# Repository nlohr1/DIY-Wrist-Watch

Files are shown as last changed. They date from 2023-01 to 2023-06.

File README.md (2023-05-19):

# DIY-Wrist-Watch
### Small 3D-Printed OLED-Clock with RTC and ATmega328-chip, based on Arduino-code

Small OLED-Clock with the small **8-pin** Real-Time chip DS3231**MZ** and the commonly known (Arduino) ATmega328 uController chip,
in conjunction with a 128x64px OLED-Display (SSD1306-chip) - displaying Date, Time, (Battery)-Voltage and Skin-Temperature.

----
**OLED-Clock Case & Foto:**  
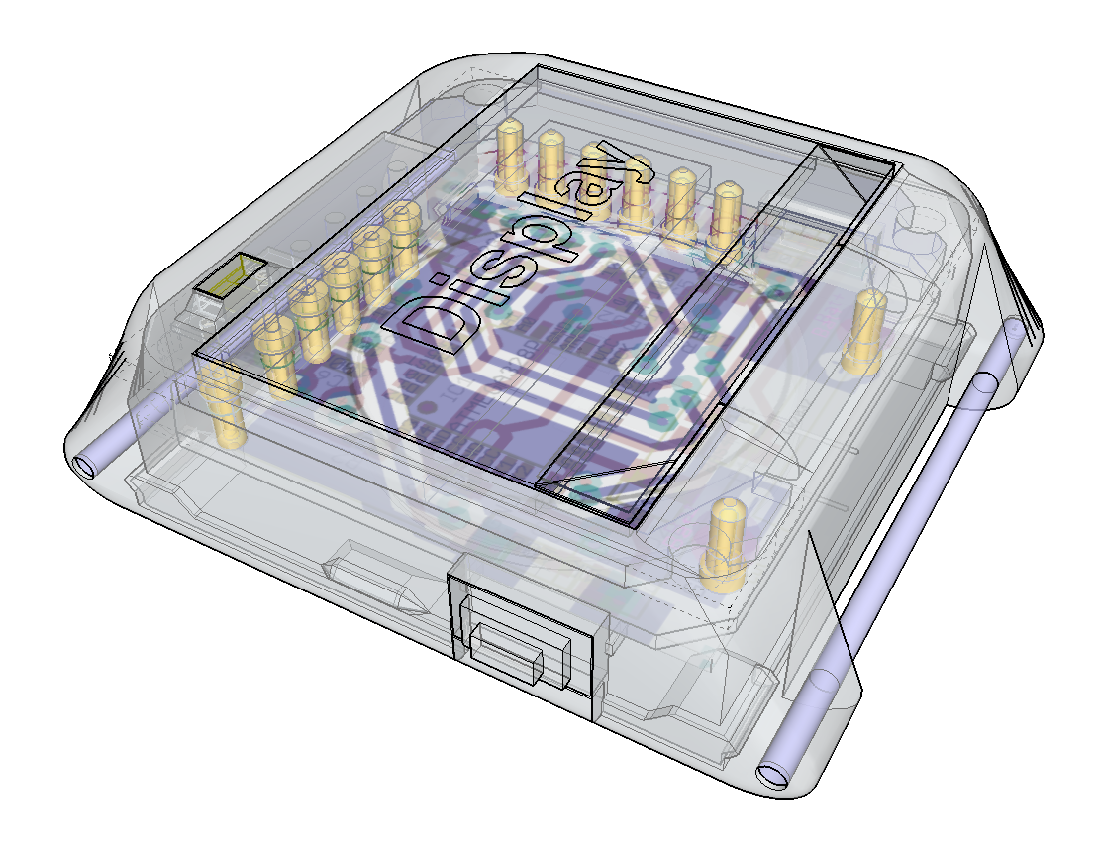
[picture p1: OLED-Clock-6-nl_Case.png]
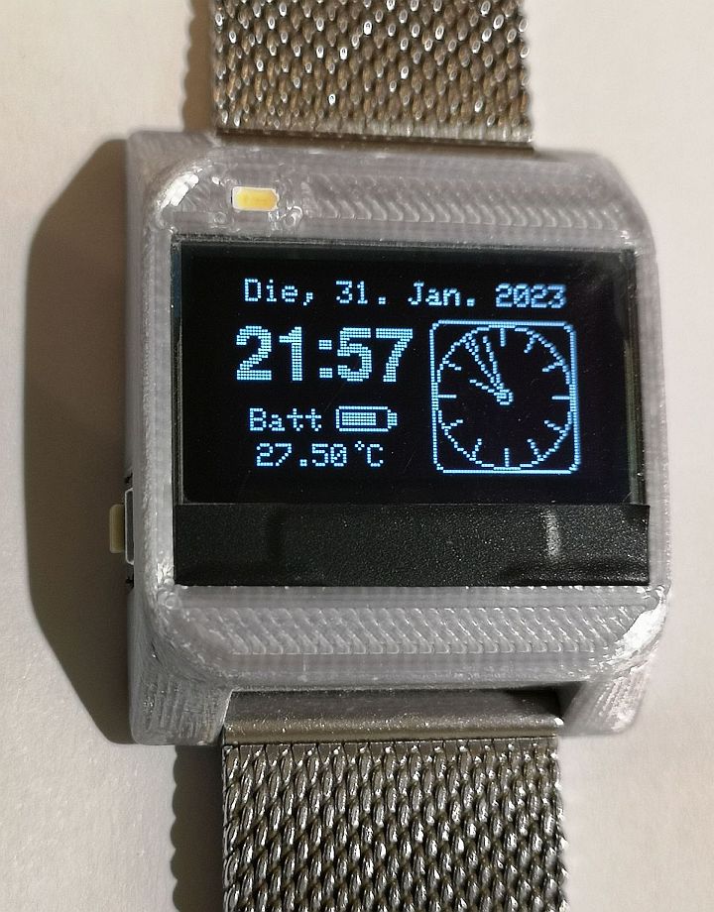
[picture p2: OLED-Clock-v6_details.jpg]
   

**Schematic:**  
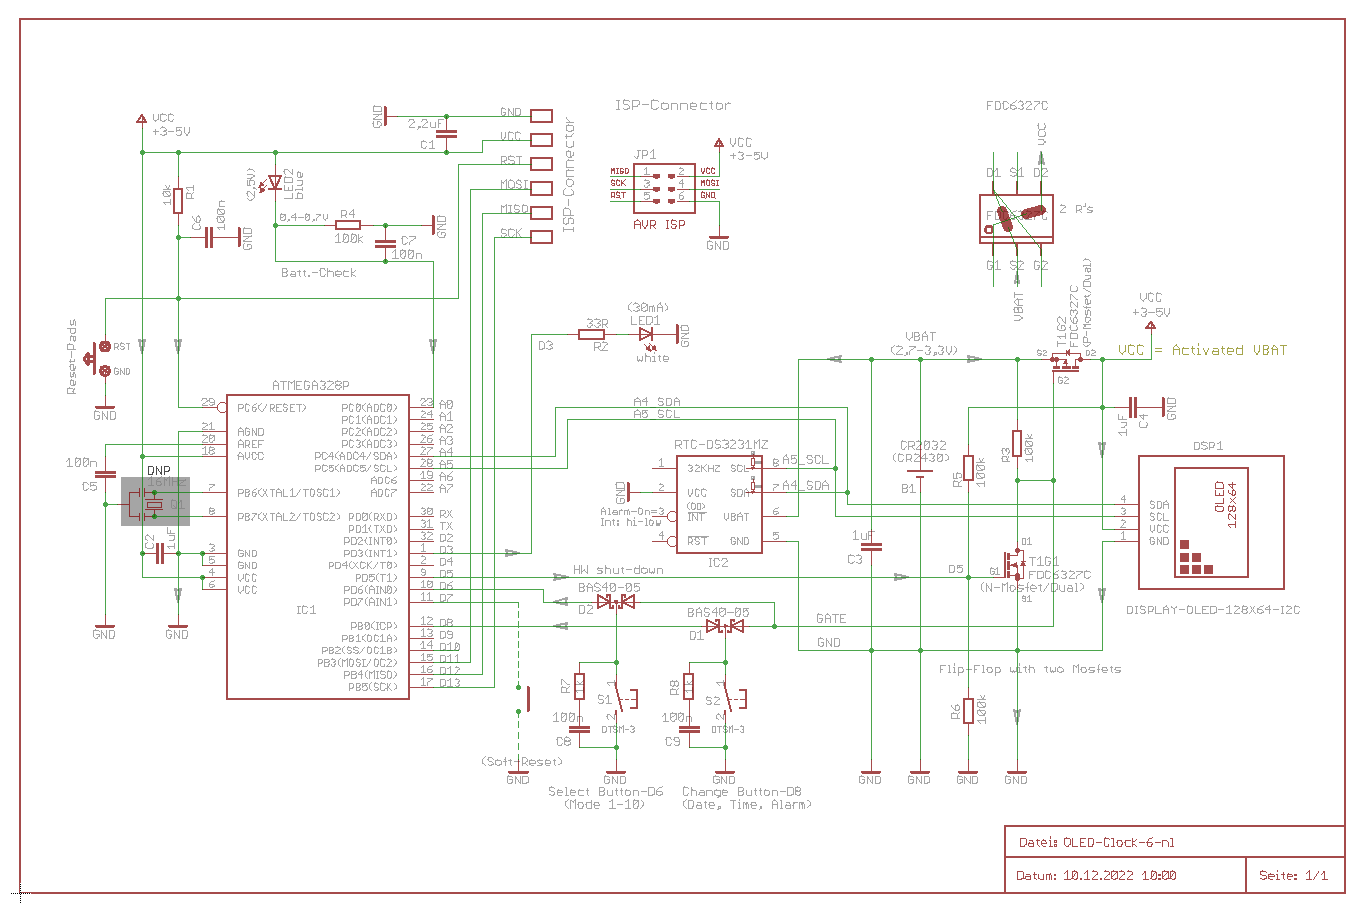
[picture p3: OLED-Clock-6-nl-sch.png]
  

**PCB-Layout:**  
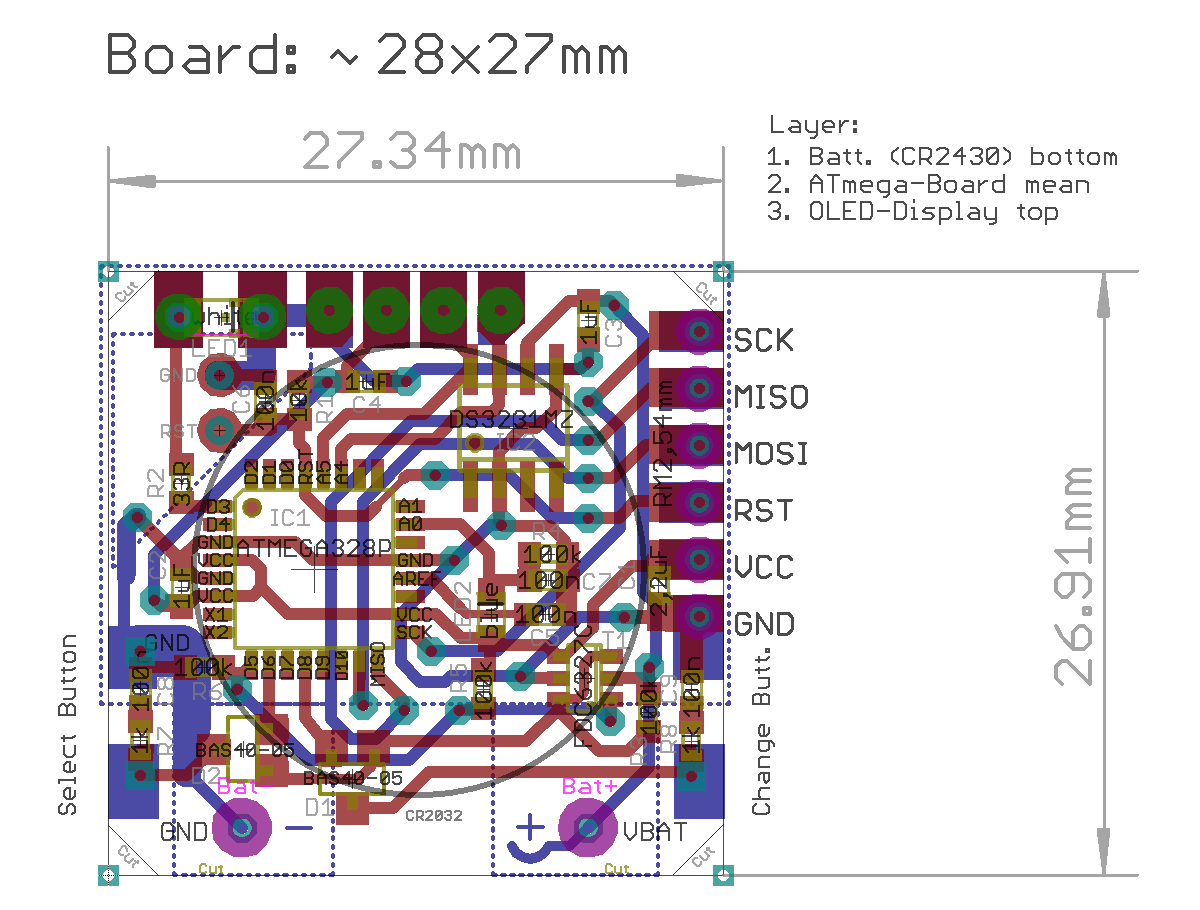
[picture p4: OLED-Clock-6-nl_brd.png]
  
Att: Push-Buttons soldered on PCB-background! - Female Socket-headers (yellow bushings) soldering: see "OLED-Clock-6-nl_Case.png"!

----
### Partlist (BOM) for "OLED-Clock-6-nl.sch":  
<pre><b><code>Qty.  Components      Value          Description                                        Package</code></b><code>
1x     C1              2,2uF          Capacitor, SMD                                     C0603
3x     C2,C3,C4        1uF            Capacitor, SMD                                     C0603
5x     C5,C6,C7,C8,C9  100n           Capacitor, SMD                                     C0603
2x     D1,D2           BAS40-05(W)    Dual-Schottky-Diode, low-leakage (1uA), SMD        SOT23 (-323-R)
1x     IC1             ATMEGA328P     8-bit Microcontroller (4x8 = 32 Pin), SMD          TQFP32-08
1x     IC2             DS3231MZ       RTC Real-Time Clock (8-Pin), SMD                   SO08
1x     JP1             AVR-ISP-6      AVR ISP-6 Serial Programming Header                AVR-ISP-6
1x     LED1            cool-white     Osram-LED-Duris-E3, 2.240mcd, 3V/30mA, SMD-3014    Chipled 1206
1x     LED2            blue           High-Efficiency LED, 2.5V-forward-voltage, SMD     Chipled 0805
1x     MD1             OLED-Display   I2C OLED-Module 0.96", (SSD1306 chip), SMD         128x64px
1x     R1              10k            Resistor, SMD                                      R0603
1x     R2              33R            Resistor, SMD                                      R0603
4x     R3,R4,R5,R6     100k           Resistor, SMD                                      R0603
2x     R7,R8           1k             Resistor, SMD                                      R0603
2x     S1,S2           Push-Button    Micro Tactile Switch 12V, 50mA, SMD                3.7x6x2.5mm
1x     T1              FDC6327C       Dual N+P-Channel Mosfet, SMD                       SOT23-6
14x    Socket          1x40 Pin       Female Socket-header, short (L:7.0mm, hole:0.6mm)  RM:2,54mm
1x     Board           FR4 #0.8mm     Mainboard, 2-layer (Cu 35um), #0.8mm               27.3x26.9mm
1x     Case            PLA or PETG    3D printed, 0.13mm layer-height, 100% Infill       31x36x10mm
1x     Lid             PLA or PETG    Bottom-Lid, case-latching                          29x28x2mm
1x     Strap           Inox           20mm Quick Release Milanese Mesh Watch Band        width: 20mm
2x     Wire            Inox or Steel  Inox or Galvanized Steel-Wires ø1.2mm              L: 29mm
2x     Bushing         Inox or Steel  Inox- or Brass-Bushing, ø1.8/1.5 mm                L: 20mm
</code></pre>   

----
Both, Micro-Processor and OLED are switched-on at Button-press, and off/disconnected from Battery **per hardware** (Schmitt-Trigger Transistor-circuit) after about 8 seconds, so that the only remaining consumption comes from RTC-chip (in stand-by-mode), consuming less than 1uA.  

I resigned to use the uControllers software-"power-down"-function, because this does not disconnect the OLED-display(chip) and other chips on board from Battery, which are causing additional power-consumptions.  
Current-Leakages are minimized through the double-mosfet FDC6237 (small Gate-Capacitances and Gate Threshold Voltages with 1-2V) and two double-diodes (BAS40-05W) with very small leakage-currents of 20nA.  
With this configuration the CR2032-Lithium-Battery lasts more than 2 years (proved! - using the clock-display about 10 times/day).

The Clock additionally provides a calendar, displaying the actual month(days) and a relatively bright Flashlight-LED, consuming only about 10mA.

Two Buttons are handling the Display-"On", Calendar, FlashLight-On/Off and Set/Reset of the Clock, meanwhile Display-"Off" is done automatically after 8 seconds.
The code is subdivided in several sections, with jump-markers: §0, §1, §2... explained in the code-head.  
I commented every line of the software, so it's possible to understand and modify it (at your own "risk")...  
File "OLED-Watch-6-nl-Manual.txt" provides a short user-manual list.  

The Software program-code (Arduino-based C++) is flashed through an ISP-Programmer to the ATmega328-Chip - **without bootloader**, to save start-time.  
To flash the chip I use the known **avrdude** as command-line-program, flashing the (Arduino-compiled) resulting hex-file with an ISP-Programmer (USBasp or similar), this programmer connected on one side through USB to my Notebook and on the other through a 6-pole ISP-Connector-Socket to the 6 Clock-pcb-board bushings.  

Avrdude command lines to flash the code into the ATmeag328-chip are explained also on the end of the program-file:  

> **"OLED-Clock-w-Led-and-Calendar.ino"** *(open/edit this file with a Text-Editor like Notepadd++)*  
> &nbsp; or directly in the Arduino-GUI, then compile it and

use the .hex-result in following command-line:  
> avrdude.exe -v -V -p m328p -c usbasp -B10 -e -D -U flash:w:OLED-Clock-w-Led-and-Calendar.ino.hex:i

The Case, Lid and battery-Holder are 3D-Printed with 0.13mm Layer-height and 100% Infill (PLA: 210°C / 60°C). I provided .stl-files of case, lid and battery-holder, also the corresponding .gcode-files for a medium 3D-Printer (bed-size about: 220 x 220 mm), as beeing Prusa-MK3 or similar printers like Anycubic-Pro, etc. (negligible differences in bed-sizes).

- Sliced with Prusa-Slicer - my profile-file: "prusaslicer_config.ini" - you may load it with the Hotkey [Ctr+L] into the Prusa-Slicer...  

- PCB schematic and Layout: Eagle 7.4
- Prototype etched with 0.8mm FR4-board with Toner-Direct methode (2 layers: first CNC-drilled the FR-material, (blank/fine-sanded + cleaned with acetone), then transferred the layout with toner-transfer-paper: 2 layers fixed/congruented on the 4 outer-edges/holes with ø0.4mm needles, this needles exchanged with ø0,4mm clamping-wire, fixing the paper on the FR4-board also with kapton-band on top and both sides, this "sandwitch" then toner-laminated with a 200°C modified laminator, etched in sodium persulfate at 70-80°C (etching-result in ≈ 5-10 min) + finally hot-tinned both sides with a flat soldering iron.
---

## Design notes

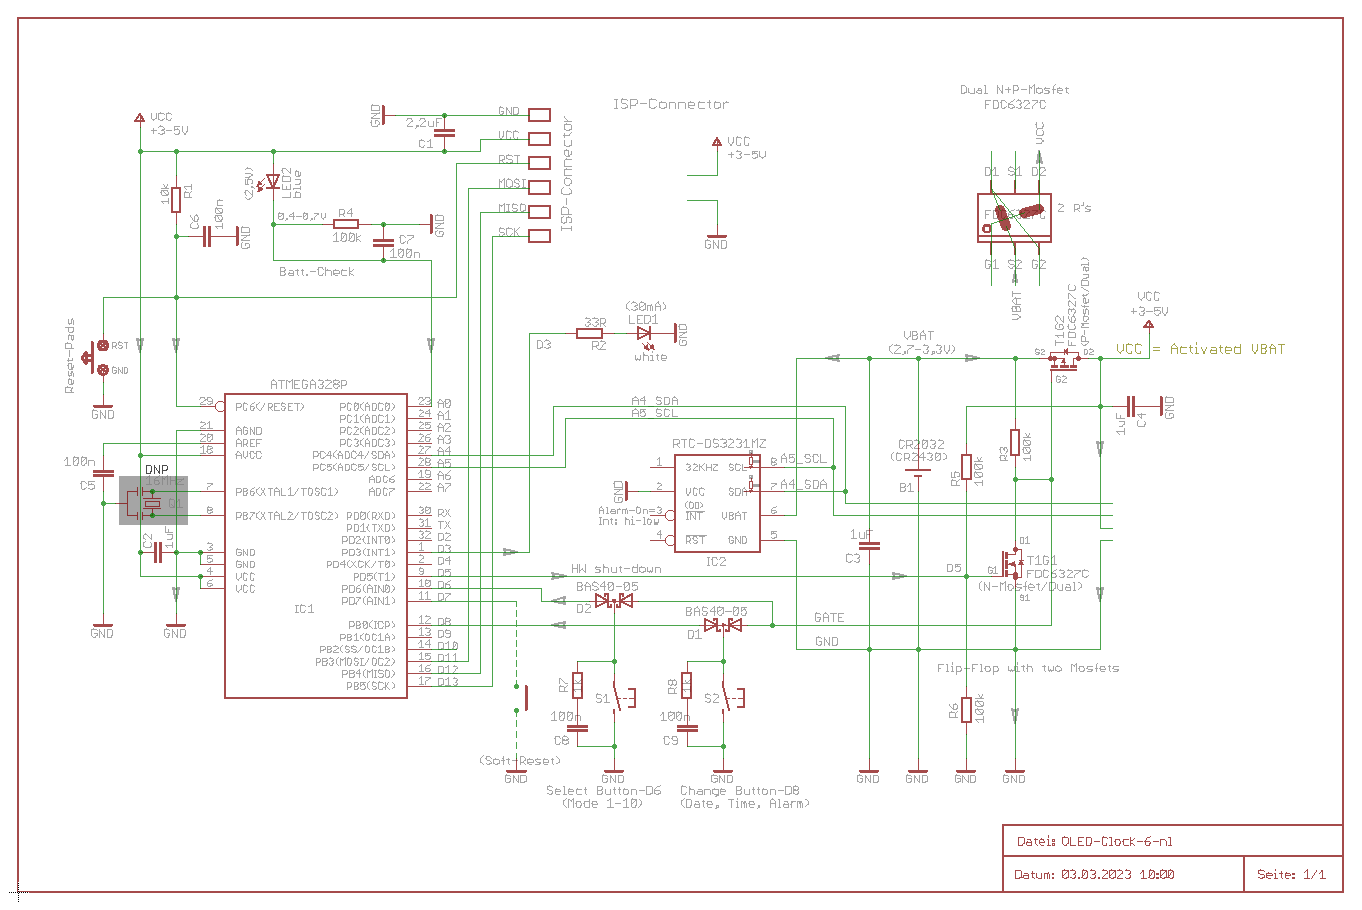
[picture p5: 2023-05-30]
OLED-Clock-6-nl_sch.png

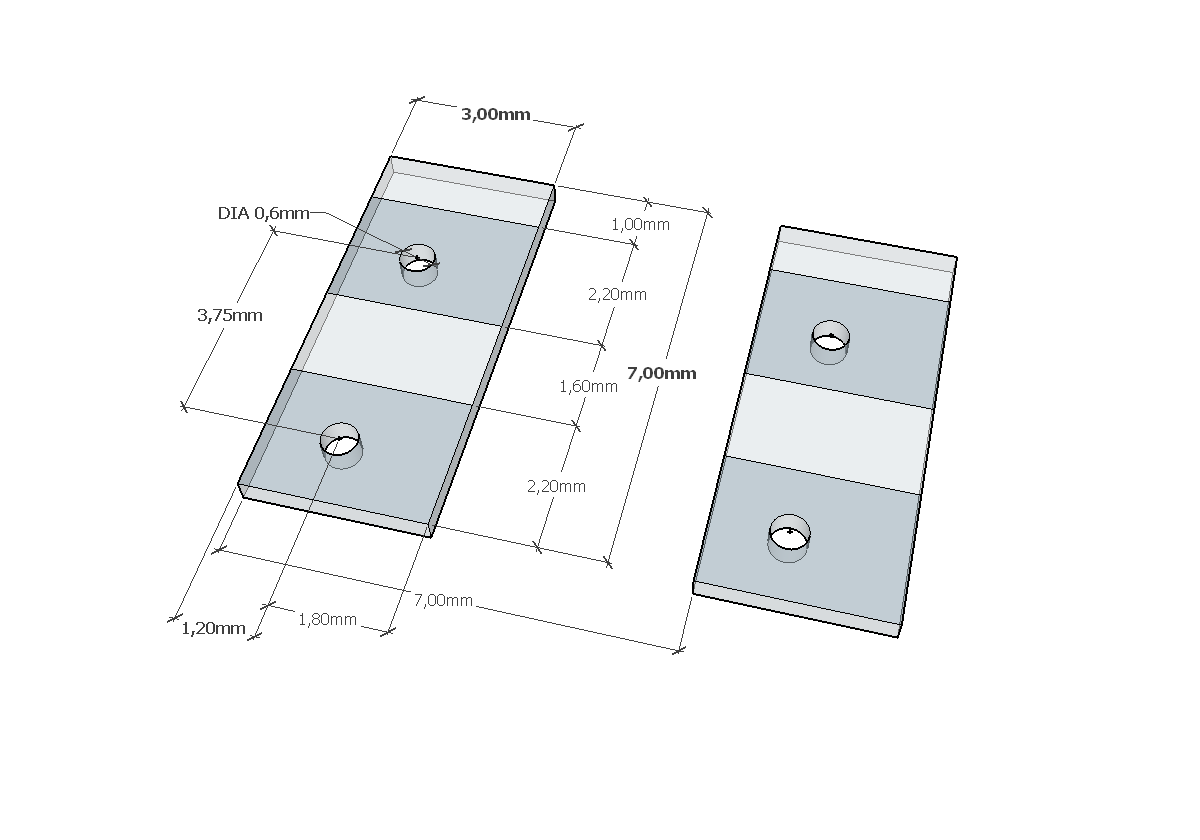
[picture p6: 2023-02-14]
LED-Platinchen_04mm_3x7mm.png

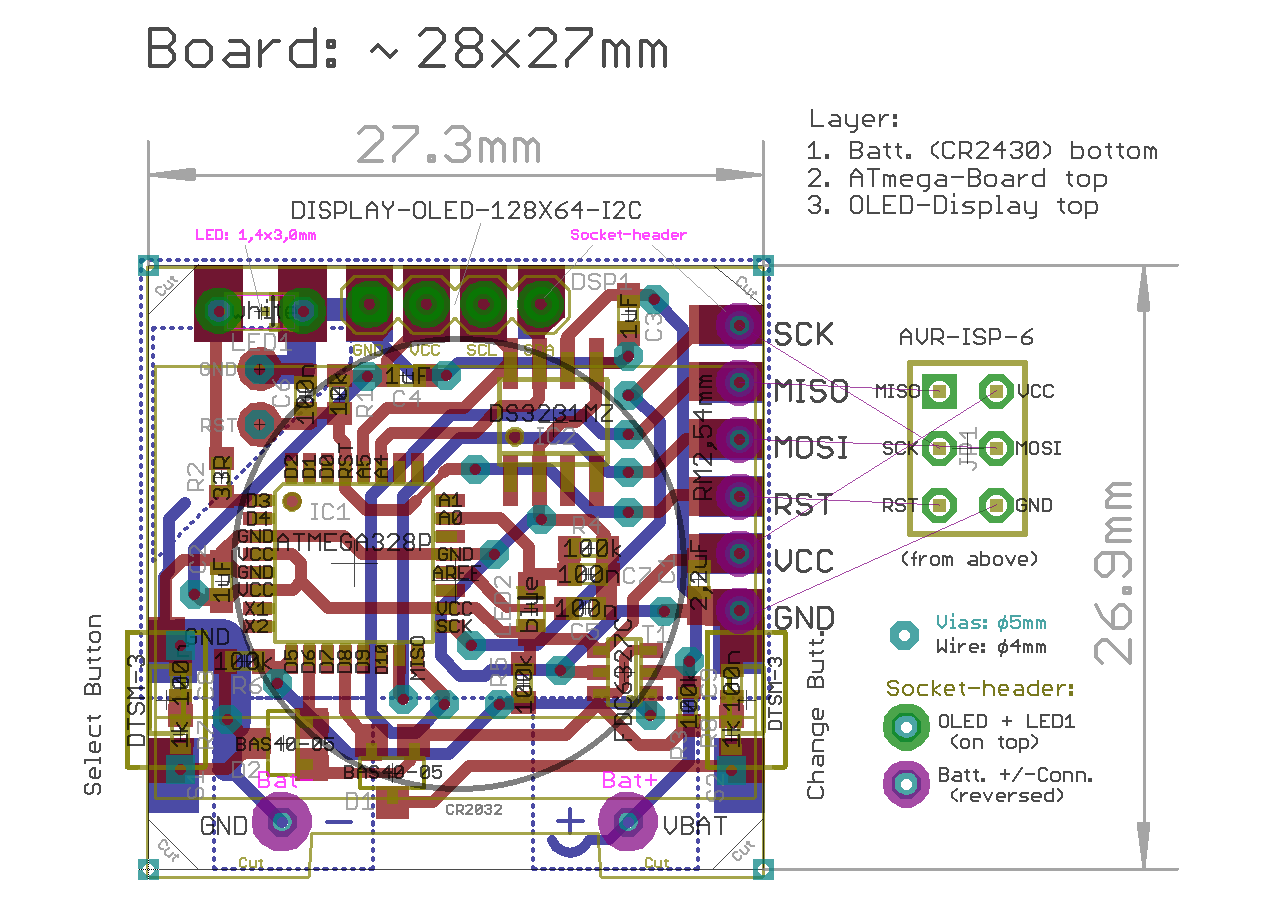
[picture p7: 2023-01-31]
OLED-Clock-6-nl-brd.png

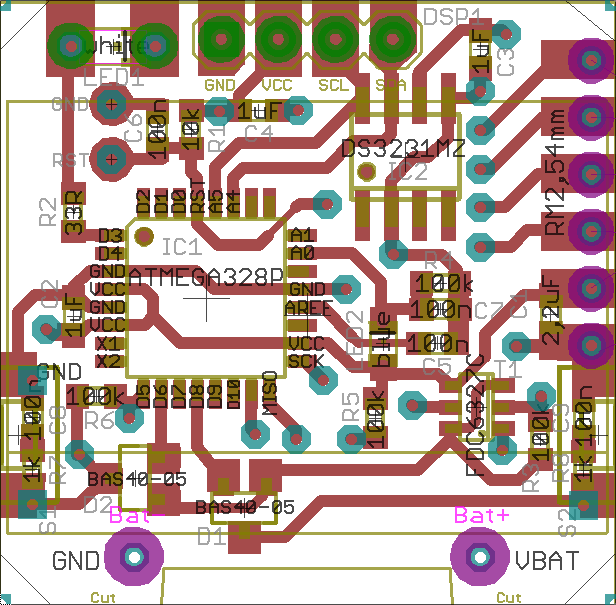
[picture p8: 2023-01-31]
OLED-Clock-6-nl-Board_Top.png

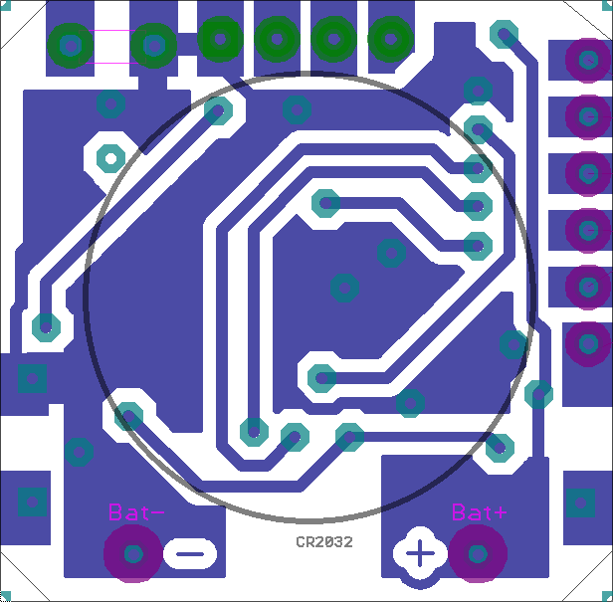
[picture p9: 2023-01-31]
OLED-Clock-6-nl-Board_Bot.png

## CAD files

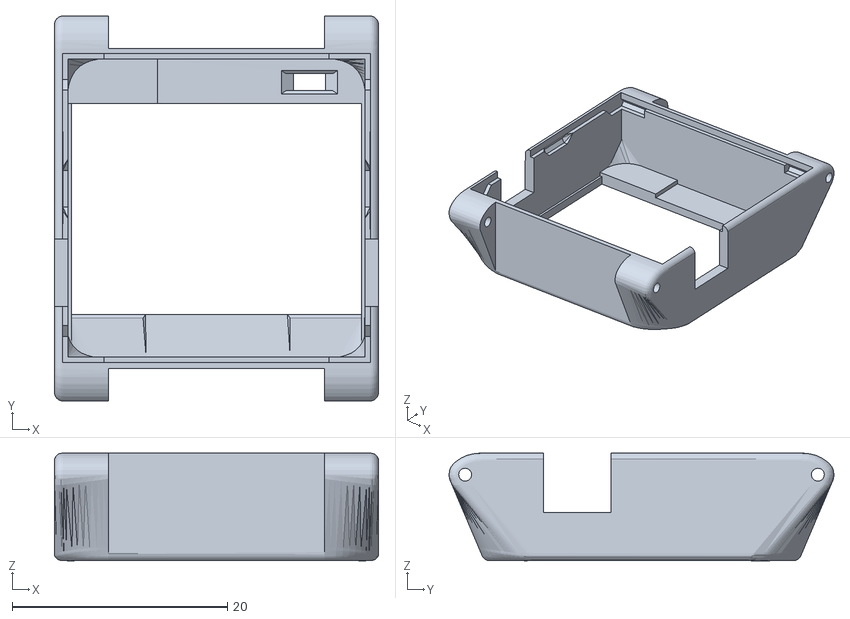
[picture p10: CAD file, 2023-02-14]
OLED-Clock-6-nl_Case.stl
30.2 x 35.8 x 10.0

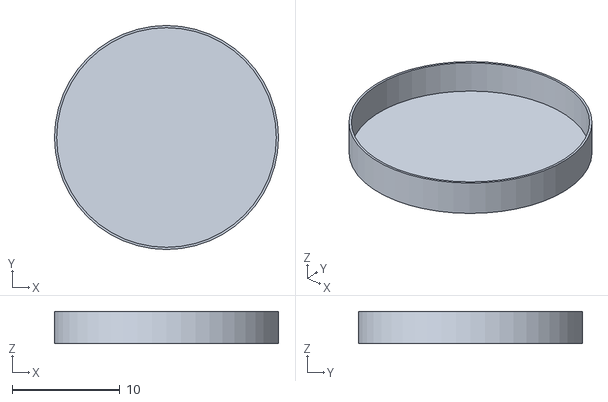
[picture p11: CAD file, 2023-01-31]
OLED-Clock-6-nl_Batt_0.2mm.stl
20.8 x 20.8 x 3.00

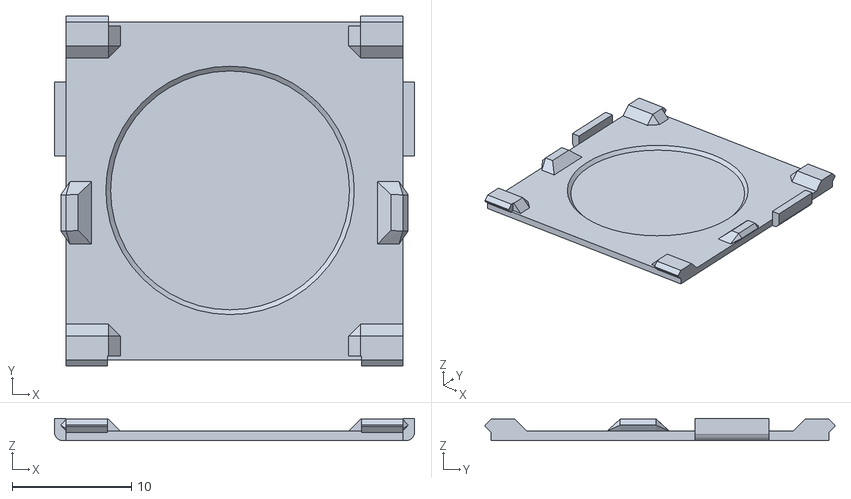
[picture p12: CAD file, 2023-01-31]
OLED-Clock-6-nl_Lid.stl
30.1 x 29.3 x 1.87

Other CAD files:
LED-Platinchen_04mm_3x7mm.skp
OLED-Clock-6-nl_Batt_0.2mm.skp
OLED-Clock-6-nl_Case.skp

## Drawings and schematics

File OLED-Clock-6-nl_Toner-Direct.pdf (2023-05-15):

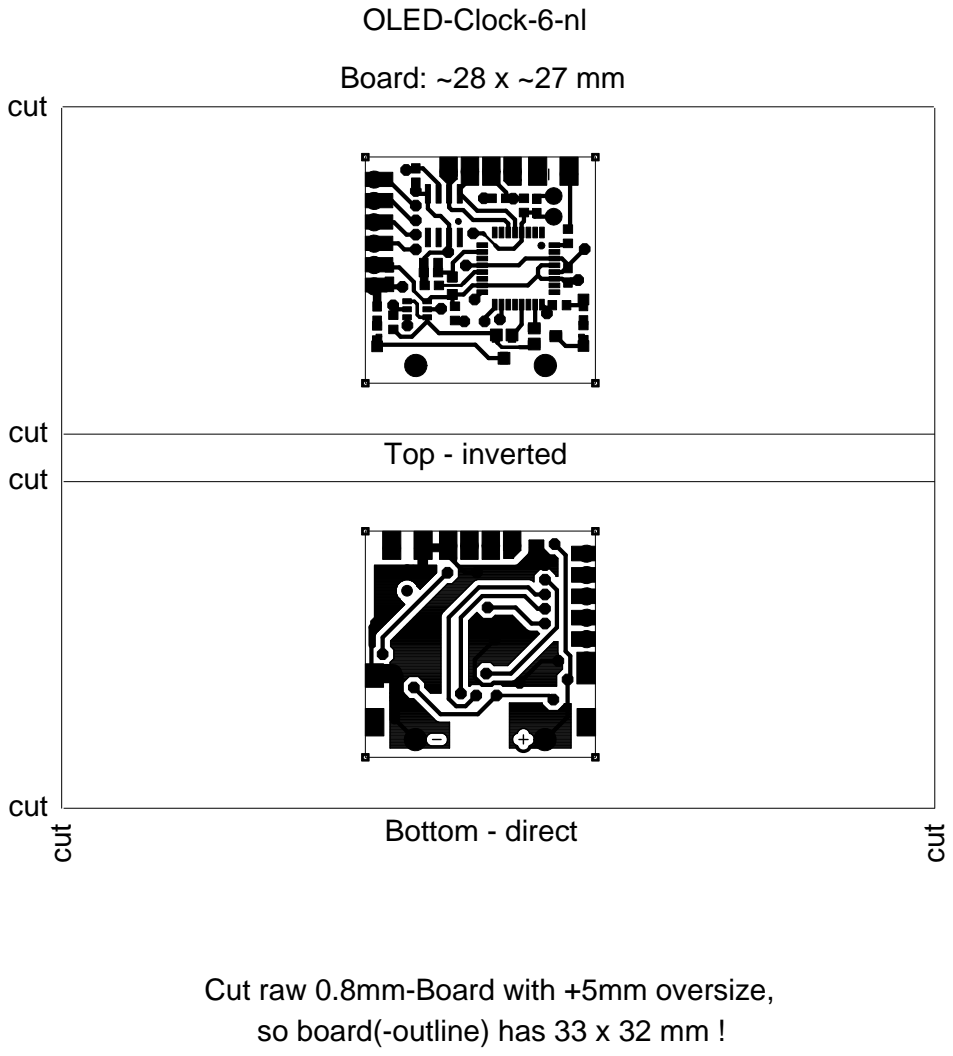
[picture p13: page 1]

Cut raw 0.8mm-Board with +5mm oversize,
so board(-outline) has 33 x 32 mm !

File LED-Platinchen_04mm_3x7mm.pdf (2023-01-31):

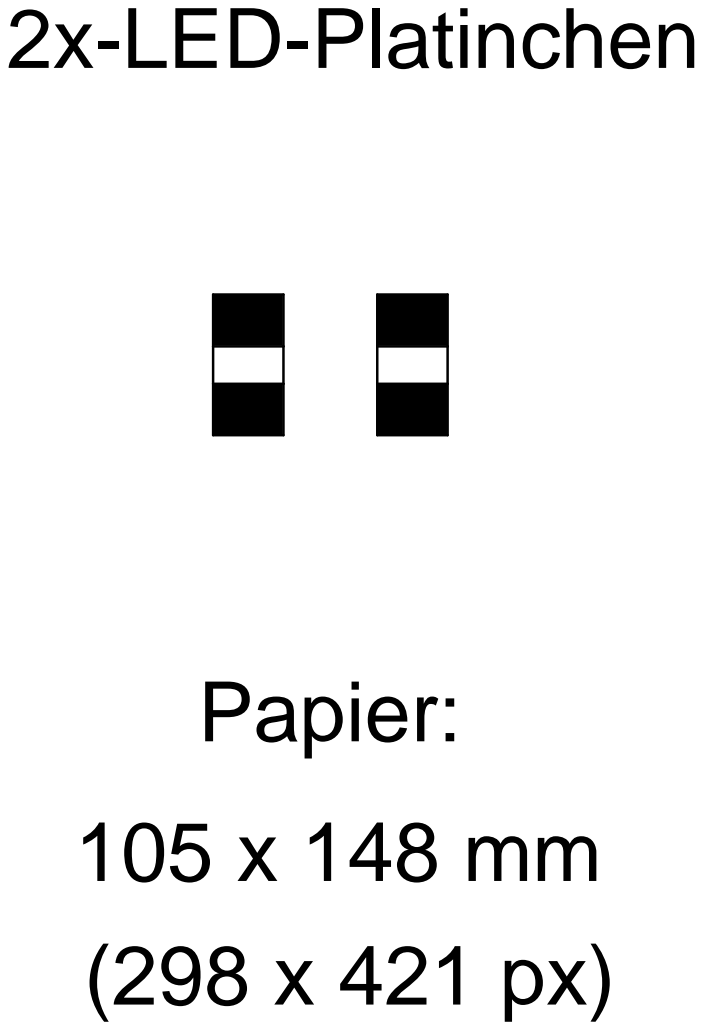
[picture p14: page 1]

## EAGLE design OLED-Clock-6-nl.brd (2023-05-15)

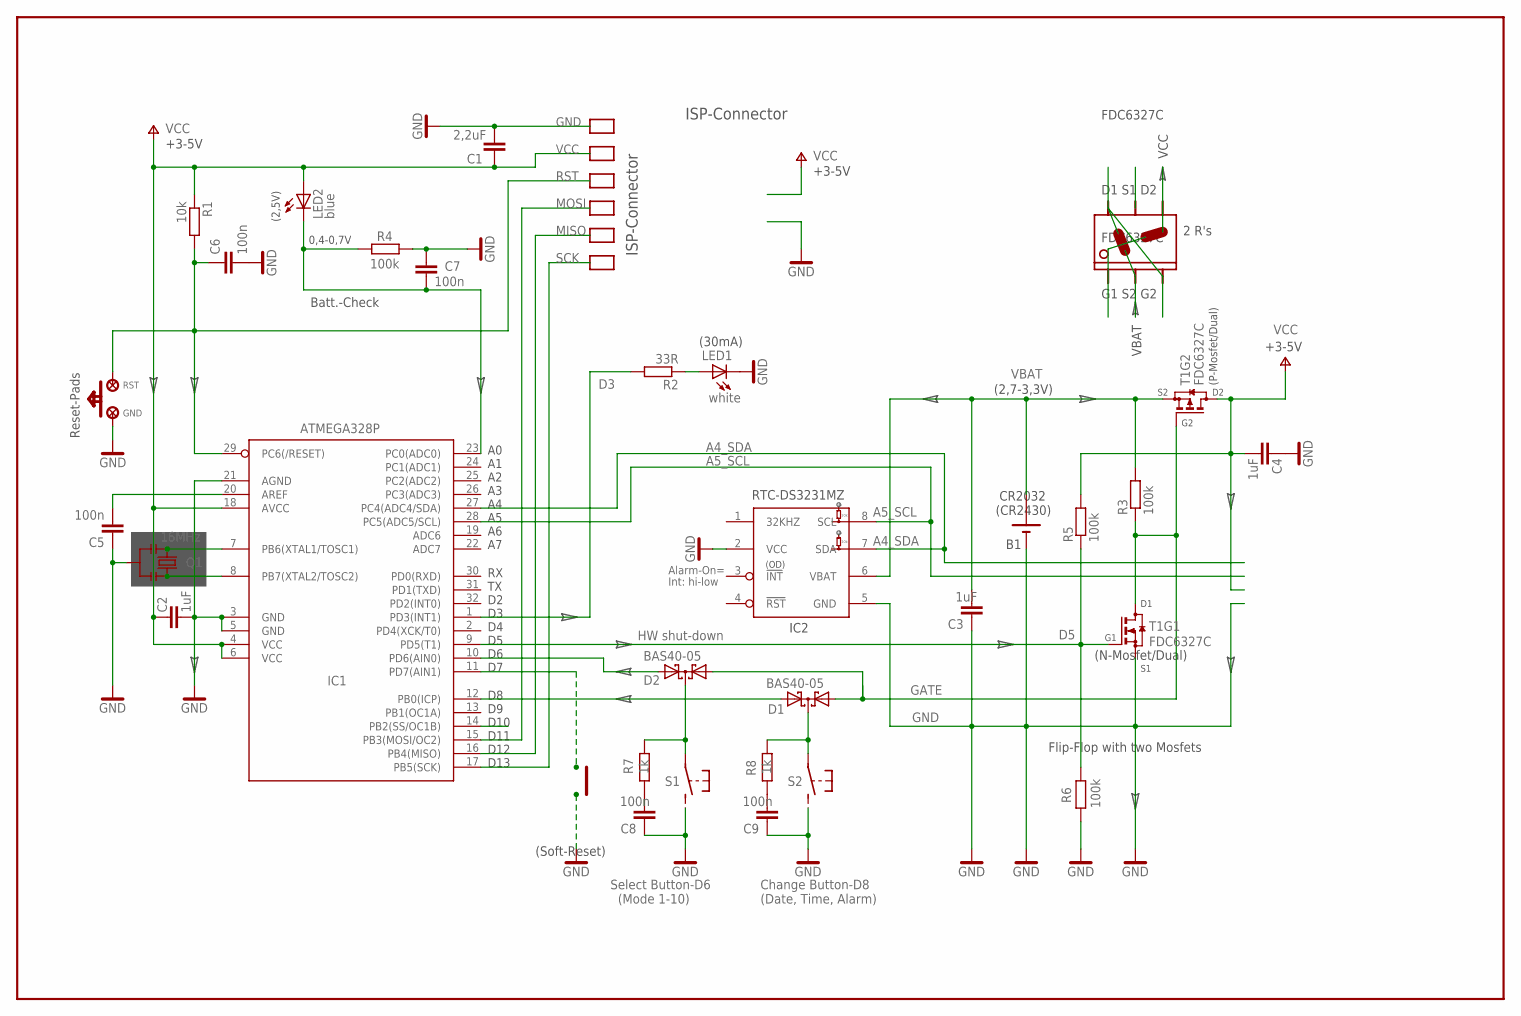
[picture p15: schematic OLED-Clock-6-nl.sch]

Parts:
C1: 2,2uF; C0603
C2, C3, C4: 1uF; C0603
C5, C6, C7, C8, C9: 100n; C0603
D1, D2: BAS40-05; SOT23
GND: LSP20
IC1: ATMEGA328P; TQFP32-08
IC2: DS3231MZ; SO08
LED1: white; CHIPLED_1206
LED2: blue; CHIPLED_0805
R1: 10k; R0603
R2: 33R; R0603
R3, R4, R5, R6: 100k; R0603
R7, R8: 1k; R0603
RST: LSP20
T1: FDC6327C; SOT23-6

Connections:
A0: C7.1, IC1.23 (PC0(ADC0)), LED2.C, R4.1
A4_SDA: IC1.27 (PC4(ADC4/SDA)), IC2.7 (SDA)
A5_SCL: IC1.28 (PC5(ADC5/SCL)), IC2.8 (SCL)
D3: IC1.1 (PD3(INT1)), R2.2
D5: IC1.9 (PD5(T1)), R5.1, R6.2, T1.1 (G)
D6: D2.2 (A2), IC1.10 (PD6(AIN0))
D7: IC1.11 (PD7(AIN1))
GATE: D1.1 (A1), D2.1 (A1), R3.1, T1.3 (G), T1.6 (D)
GND: C1.2, C2.2, C3.1, C4.1, C5.1, C6.2, C7.2, C8.1, C9.1, GND.P$1, IC1.3 (GND), IC1.5 (GND), IC1.21 (AGND), IC2.2 (VCC), IC2.5 (GND), LED1.C, R4.2, R6.1, T1.5 (S)
MISO: IC1.16 (PB4(MISO))
MOSI: IC1.15 (PB3(MOSI/OC2))
unnamed: D2.3 (C), R7.2
unnamed: C5.2, IC1.20 (AREF)
unnamed: D1.3 (C), R8.2
unnamed: D1.2 (A2), IC1.12 (PB0(ICP))
unnamed: LED1.A, R2.1
unnamed: C8.2, R7.1
unnamed: C9.2, R8.1
RST: C6.1, IC1.29 (PC6(/RESET)), R1.2, RST.P$1
SCK: IC1.17 (PB5(SCK))
VBAT: C3.2, IC2.6 (VBAT), R3.2, T1.2 (S)
VCC: C1.1, C2.1, C4.2, IC1.4 (VCC), IC1.6 (VCC), IC1.18 (AVCC), LED2.A, R1.1, R5.2, T1.4 (D)
X1: IC1.7 (PB6(XTAL1/TOSC1))
X2: IC1.8 (PB7(XTAL2/TOSC2))

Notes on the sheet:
RTC-DS3231MZ
A0 A1 A2 A3 A4 A5 A6 A7
RX TX D2 D3 D4 D5 D6 D7
D8 D9 D10 D11 D12 D13
ISP-Connector
Select Button-D6 (Mode 1-10)
Change Button-D8 (Date, Time, Alarm)
HW shut-down
Batt.-Check
CR2032 (CR2430)
(P-Mosfet/Dual)
0,4-0,7V
IC2
(N-Mosfet/Dual)
(2,5V)
+3-5V
Alarm-On= Int: hi-low
Flip-Flop with two Mosfets
10k
(30mA)
(Soft-Reset)
(OD)
16MHz
G1 S2 G2
D1 S1 D2
FDC6327C
2 R's
VCC
VBAT
Reset-Pads
(2,7-3,3V)

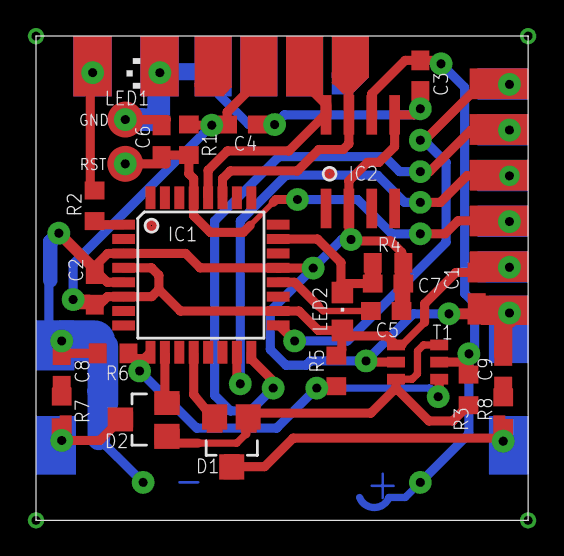
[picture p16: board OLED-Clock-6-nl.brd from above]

Board: 2 copper layers, 27.3 x 26.9 mm, 26 parts (0 on the bottom side), 18 nets.

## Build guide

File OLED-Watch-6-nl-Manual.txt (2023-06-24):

OLED-WristWatch-5-nl - Manual:
==============================
This OLED-Clock has a Date+Time Display, a Flashlight and a Calendar of actual month+day.
The Display is dimmed at night between 11:00PM and 7:00AM  (23:00h and 07:00h).

Function of the 2 Buttons (1 on the right-side and 1 on the left-side):
=========================

⇒ CHANGE-Button D8, (right-side), pressing:
-------------------------------------------
  1st press = Clock-Display "On": displays time+date
  2nd press = light-up Flashlight-Torch
  3rd press = return to Clock-Display / toggling Clock ⇔ Flashlight

⇒ SELECT-Button D6 (left-side), pressing:
-----------------------------------------
  1st press = Calendar-Display of actual month
  1st press = return to Clock-Display / toggle Clock ⇔ Calendar

Clock-Settings:
---------------
If Button-D6 (left-side) is pressed more than 0.5 seconds, display shows
Clock-Settings:

  1x long = Time and Date-Settings
  2x long = return to Normal-mode (Clock-Display)

SetClock-Display:
  - set dow
  - day
  - year
  - hours
  - minutes
  - seconds

To change seconds, set the clock +1 minute, then press Button-D8 at 59 seconds
to synchronize to external "0"-time.

FlashLight:
-----------
If right Button (D8) is pressed, the built-in FlashLight lights-up

Month-Calendar:
---------------
If left Button (D6) is pressed, an actual Month-Calendar is displayed. If one of
the two Buttons are pressed again, Calendar returns to Clock-Display.

Battery:
--------
A normal CR2032 Lithium-Battery (ø20x3.2mm) provides about 200mAh Power.
Contacts are made of insert-wire ø0.6mm, soldered to a thin ø0.2mm-wire.
The Battery-Symbol indicates the approx. level of the battery (3,2V=full, 2,4V=empty).
The Clock is working with voltages from +5.0V down to +2.0V (default: 3.0V).
The Flash-LED works from max. +4.0V down to +2.7V. Do not activate with 5.0V!
Both, uProcessor and RTC are 5V-tolerant (+5V to program the uC with Serial-USB
through ISP-connection.

!! Warning !!:
--------------
Don't recharge CR2032 Lithium-Ion-Batteries! They are recycleable, but
non-rechargeable - if charged, they may explode or burn!
